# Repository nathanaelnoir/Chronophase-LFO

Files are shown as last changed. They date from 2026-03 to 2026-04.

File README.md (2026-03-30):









# Chronophase LFO

Chronophase LFO is a clock-synced Eurorack modulation source with an Arduino Nano core, four front-panel controls, one clock input, and separate unipolar, bipolar, and inverted bipolar outputs.

## Contents

- Overview
- Features
- Quick start (KiCad 9)
- Files
- Build & assembly notes
- Testing
- License & contributing

## Overview

This repository contains the KiCad 9 design files for Chronophase LFO, a clocked modulation module for Eurorack. An external clock drives the LFO core, the four main controls adjust `WAVEFORM`, `AMP`, `PHASE`, and `MODULATION`, and the output stage provides `UP_Out`, `BP_Out`, and `BP_Inv_Out` on separate jacks.

The current KiCad 9 project files are named `Synced_LFO`, and the top-level schematic title block still says `Clocked Modulation LFO`. The PCB title block currently shows revision `v0.1`, so that is the most concrete revision marker in the project as it stands.

The hardware clearly includes an `Arduino_Nano_v3.x`, but there is no firmware source in this repository at the moment, only the hardware design files.

## Features

- Clock-synced LFO built around an `Arduino_Nano_v3.x` core and `TL072` output / shaping stages.
- Four front-panel controls: `WAVEFORM`, `AMP`, `PHASE`, and `MODULATION`.
- External `CLK In` jack for sync / clock input.
- Separate `UP_Out`, `BP_Out`, and `BP_Inv_Out` outputs.
- Front-panel activity LED.
- Standard Eurorack power distribution with `+12 V / -12 V / +5 V / GND` through a 16-pin Eurorack header sheet.
- Mixed build: SMD passives, diodes, electrolytics, and SOIC op-amps, with through-hole jacks, pots, LED, and Arduino Nano.

## Quick start

1. Install KiCad 9.
2. Open the project: `KiCad/Synced_LFO.kicad_pro`.
3. Review the top-level schematic and the `EURORACK_POWER` sheet, then run ERC/DRC before exporting manufacturing files.

## Files

- `KiCad/Synced_LFO.kicad_sch` - top-level schematic
- `KiCad/eurorack_power.kicad_sch` - Eurorack power sheet
- `KiCad/Synced_LFO.kicad_pcb` - PCB
- `KiCad/Synced_LFO.kicad_pro` - KiCad 9 project file
- `KiCad/Synced_LFO.kicad_prl` - local KiCad 9 project state
- `KiCad/Synced_LFO.sch` - legacy schematic file
- `KiCad/Synced_LFO.pro` - legacy project file

Note: there is a single PCB layout file (`KiCad/Synced_LFO.kicad_pcb`) for this project.

## Build & assembly notes

- Check orientation on the `Arduino_Nano_v3.x` module before soldering headers or the board directly. The USB end and pin order matter.
- Confirm pin-1 orientation on the `TL072` packages and polarity on the diodes and electrolytics before powering the board.
- Double-check the Eurorack power header orientation before applying power. This design uses `+12 V`, `-12 V`, `+5 V`, and `GND`, so a reversed cable is an easy way to damage parts.
- Panel hardware is straightforward but still substantial: four 100 k pots, four 3.5 mm jacks, and one LED.
- This is a mixed SMD + THT build, so it makes sense to solder the low-profile SMD parts first and leave the pots, jacks, LED, and Nano for later.

## Testing

1. Power the module from a current-limited Eurorack supply and verify `+12 V`, `-12 V`, `+5 V`, and `GND` on the power section before checking the rest of the circuit.
2. Feed a known clock into `CLK In` and confirm the front-panel LED shows activity.
3. Probe `UP_Out`, `BP_Out`, and `BP_Inv_Out` on a scope and confirm all three outputs are present and distinct.
4. Turn `WAVEFORM`, `AMP`, `PHASE`, and `MODULATION` through their full range and verify the outputs respond as expected.
5. If the Arduino Nano is fitted, confirm the module behavior is stable across different clock rates and after power-cycling.

## License & contributing

No `LICENSE` file has been added to this repository yet. Until that changes, assume the design is shared for reference, not under an explicit open-source license.

If a license is added later, this section can be updated properly.

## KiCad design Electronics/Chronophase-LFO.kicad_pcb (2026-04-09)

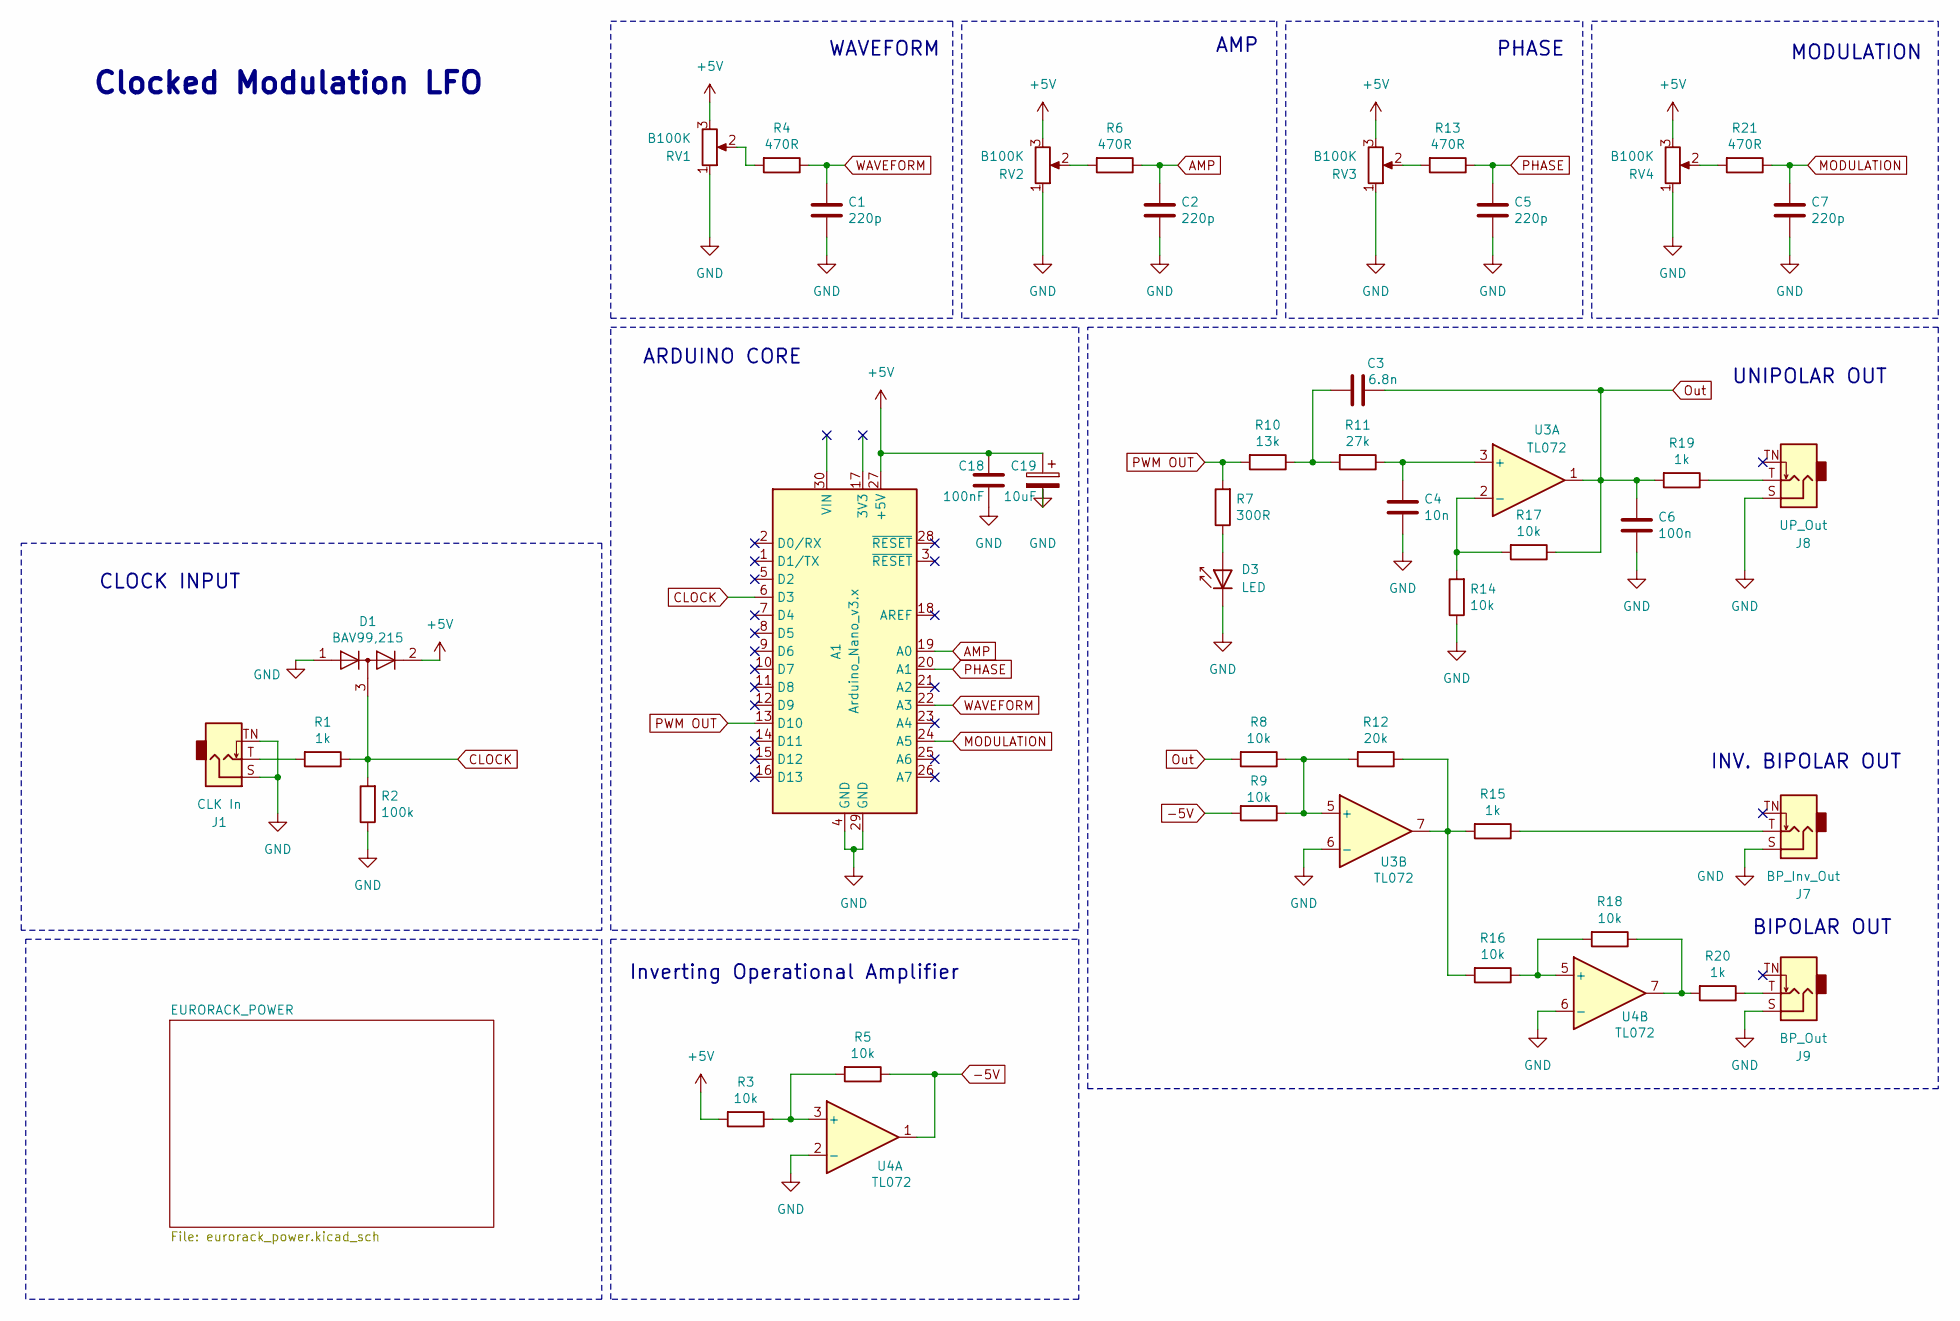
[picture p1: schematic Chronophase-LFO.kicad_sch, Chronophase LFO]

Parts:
A1: Arduino_Nano_v3.x; Arduino_Nano
C1, C2, C5, C7: 220p; C_0805_2012Metric_Pad1.18x1.45mm_HandSolder; LCSC C1530
C3: 6.8n; C_0805_2012Metric_Pad1.18x1.45mm_HandSolder; LCSC C1542
C4: 10n; C_0805_2012Metric_Pad1.18x1.45mm_HandSolder; LCSC C15195
C6: 100n; C_0805_2012Metric_Pad1.18x1.45mm_HandSolder; LCSC C1525
C18: 100nF; C_0805_2012Metric_Pad1.18x1.45mm_HandSolder
C19: 10uF; CP_Elec_5x5.4
D1: BAV99,215; SOT-23; LCSC C2500
D3: LED; LED_D3.0mm_Clear
J1: CLK In; Jack_3.5mm_QingPu_WQP-PJ398SM_Vertical
J7: BP_Inv_Out; Jack_3.5mm_QingPu_WQP-PJ398SM_Vertical
J8: UP_Out; Jack_3.5mm_QingPu_WQP-PJ398SM_Vertical
J9: BP_Out; Jack_3.5mm_QingPu_WQP-PJ398SM_Vertical
R1, R15, R19, R20: 1k; R_0805_2012Metric_Pad1.20x1.40mm_HandSolder; LCSC C11702
R2: 100k; R_0805_2012Metric_Pad1.20x1.40mm_HandSolder; LCSC C25741
R3, R5, R8, R9, R14, R16, R17, R18: 10k; R_0805_2012Metric_Pad1.20x1.40mm_HandSolder; LCSC C25744
R4, R6, R13, R21: 470R; R_0805_2012Metric_Pad1.20x1.40mm_HandSolder; LCSC C25117
R7: 300R; R_0805_2012Metric_Pad1.20x1.40mm_HandSolder; LCSC C25102
R10: 13k; R_0805_2012Metric_Pad1.20x1.40mm_HandSolder; LCSC C22797
R11: 27k; R_0805_2012Metric_Pad1.20x1.40mm_HandSolder; LCSC C25771
R12: 20k; R_0805_2012Metric_Pad1.20x1.40mm_HandSolder; LCSC C25765
RV1, RV2, RV3, RV4: B100K; Potentiometer_Alpha_RD901F_Vertical_Alt
U3, U4: TL072; SOIC-8_3.9x4.9mm_P1.27mm

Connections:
+5V: A1.27 (+5V), C18.1, C19.1, D1.2 (A), R3.2, RV1.3, RV2.3, RV3.3, RV4.3; also elsewhere on the board
-5V: R5.1, R9.2, U4.1
AMP: A1.19 (A0), C2.1, R6.1
CLOCK: A1.6 (D3), D1.3 (K), R1.1, R2.2
GND: A1.4 (GND), A1.29 (GND), C1.2, C2.2, C4.1, C5.2, C6.1, C7.2, C18.2, C19.2, D1.1 (K), D3.1 (K), J1.S, J1.TN, J7.S, J8.S, J9.S, R2.1, R14.1, RV1.1, RV2.1, RV3.1, RV4.1, U3.6 (-), U4.2 (-), U4.6 (-); also elsewhere on the board
MODULATION: A1.24 (A5), C7.1, R21.1
unnamed: C3.2, R10.1, R11.2
unnamed: D3.2 (A), R7.1
unnamed: J1.T, R1.2
unnamed: J7.T, R15.1
unnamed: J8.T, R19.1
unnamed: J9.T, R20.1
unnamed: R4.2, RV1.2
unnamed: R6.2, RV2.2
unnamed: R12.1, R15.2, R16.2, U3.7
unnamed: R13.2, RV3.2
unnamed: R18.1, R20.2, U4.7
unnamed: R21.2, RV4.2
unnamed: C4.2, R11.1, U3.3 (+)
unnamed: R14.2, R17.2, U3.2 (-)
unnamed: R8.1, R9.1, R12.2, U3.5 (+)
unnamed: R3.1, R5.2, U4.3 (+)
unnamed: R16.1, R18.2, U4.5 (+)
Out: C3.1, C6.2, R8.2, R17.1, R19.2, U3.1
PHASE: A1.20 (A1), C5.1, R13.1
PWM OUT: A1.13 (D10), R7.2, R10.2
WAVEFORM: A1.22 (A3), C1.1, R4.1

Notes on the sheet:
AMP
ARDUINO CORE
Clocked Modulation LFO
PHASE
WAVEFORM
MODULATION
INV. BIPOLAR OUT
BIPOLAR OUT
UNIPOLAR OUT
CLOCK INPUT
Inverting Operational Amplifier

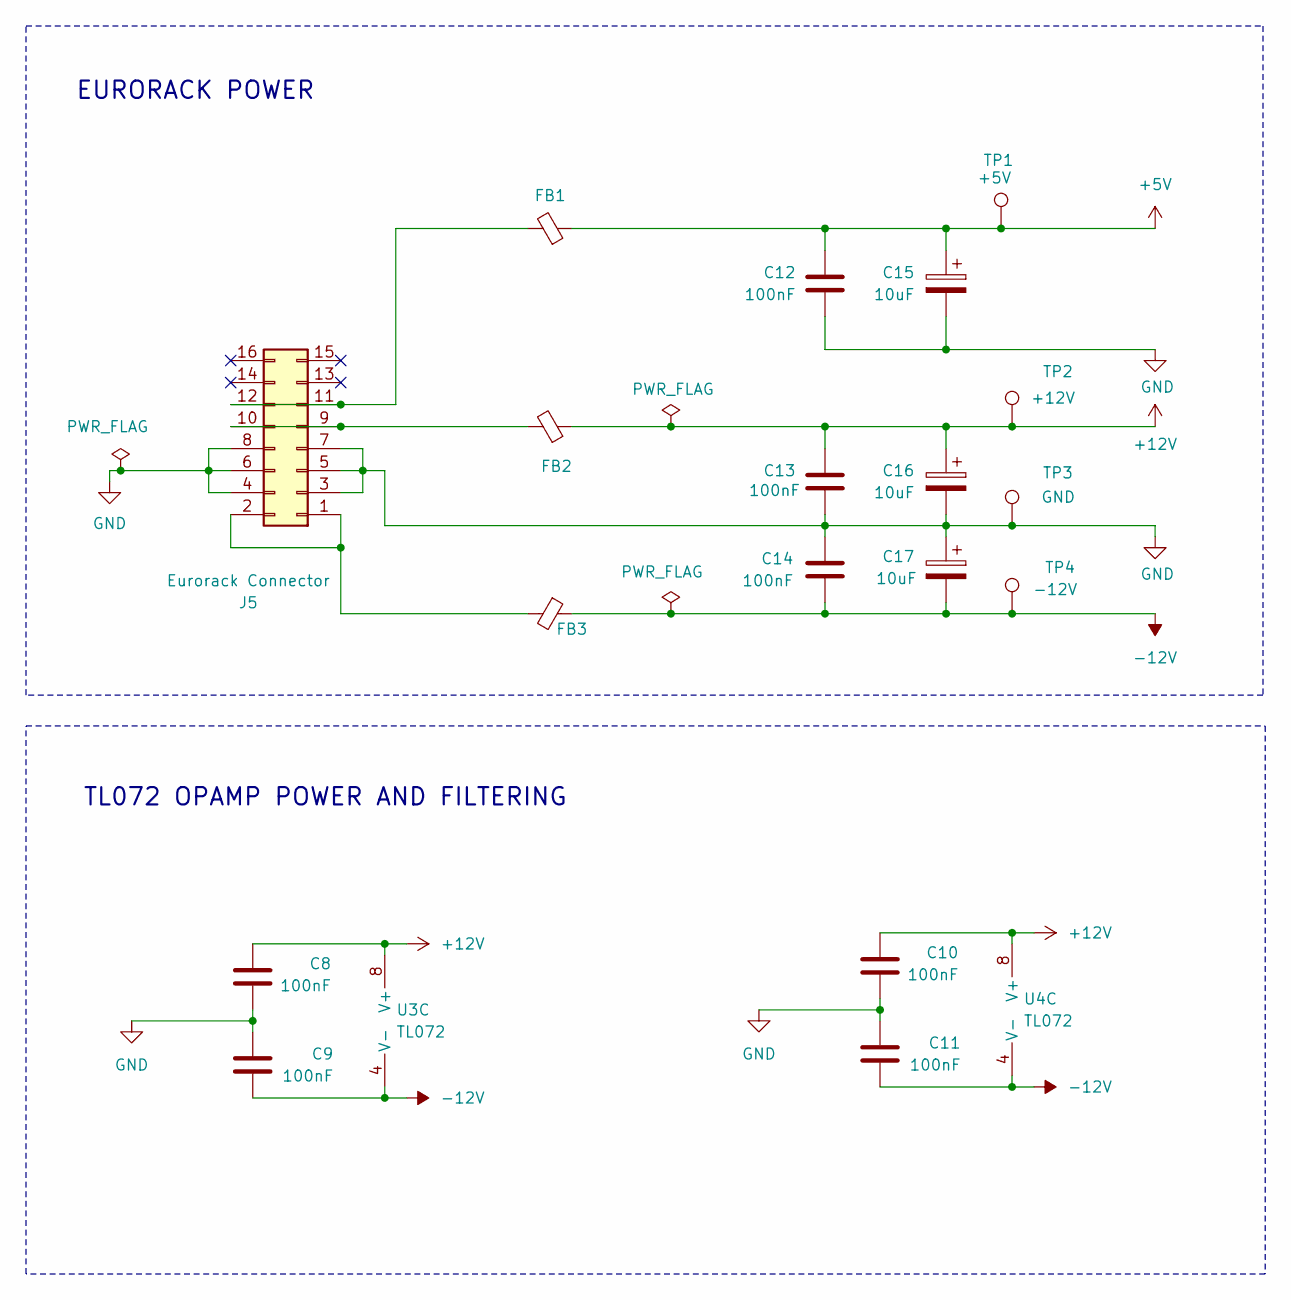
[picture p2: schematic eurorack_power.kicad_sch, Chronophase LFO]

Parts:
C8, C9, C10, C11, C12, C13, C14: 100nF; C_0805_2012Metric_Pad1.18x1.45mm_HandSolder
C15, C16, C17: 10uF; CP_Elec_5x5.4
FB1, FB2, FB3: FerriteBead_Small; L_0805_2012Metric_Pad1.05x1.20mm_HandSolder
J5: Eurorack Connector; IDC-Header_2x08_P2.54mm_Vertical
TP1: +5V; TestPoint_Pad_D1.5mm
TP2: +12V; TestPoint_Pad_D1.5mm
TP3: GND; TestPoint_Pad_D1.5mm
TP4: -12V; TestPoint_Pad_D1.5mm
U3, U4: TL072; SOIC-8_3.9x4.9mm_P1.27mm

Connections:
+5V: C12.1, C15.1, FB1.1, TP1.1; also elsewhere on the board
+12V: C8.1, C10.1, C13.1, C16.1, FB2.1, TP2.1, U3.8 (V+), U4.8 (V+)
-12V: C9.2, C11.2, C14.2, C17.2, FB3.1, TP4.1, U3.4 (V-), U4.4 (V-)
GND: C8.2, C9.1, C10.2, C11.1, C12.2, C13.2, C14.1, C15.2, C16.2, C17.1, J5.3, J5.4, J5.5, J5.6, J5.7, J5.8, TP3.1; also elsewhere on the board
unnamed: FB3.2, J5.1, J5.2
unnamed: FB2.2, J5.9, J5.10
unnamed: FB1.2, J5.11, J5.12

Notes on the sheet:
TL072 OPAMP POWER AND FILTERING
EURORACK POWER

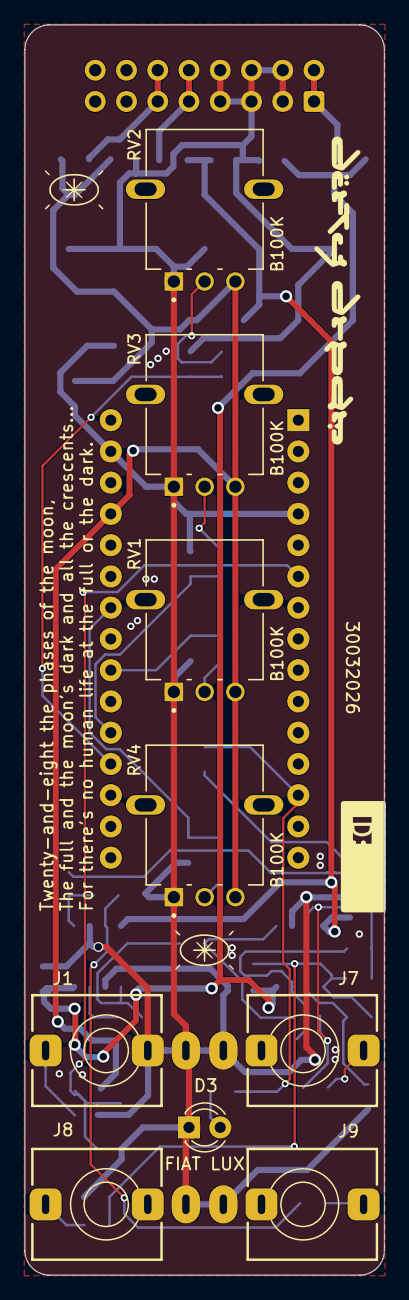
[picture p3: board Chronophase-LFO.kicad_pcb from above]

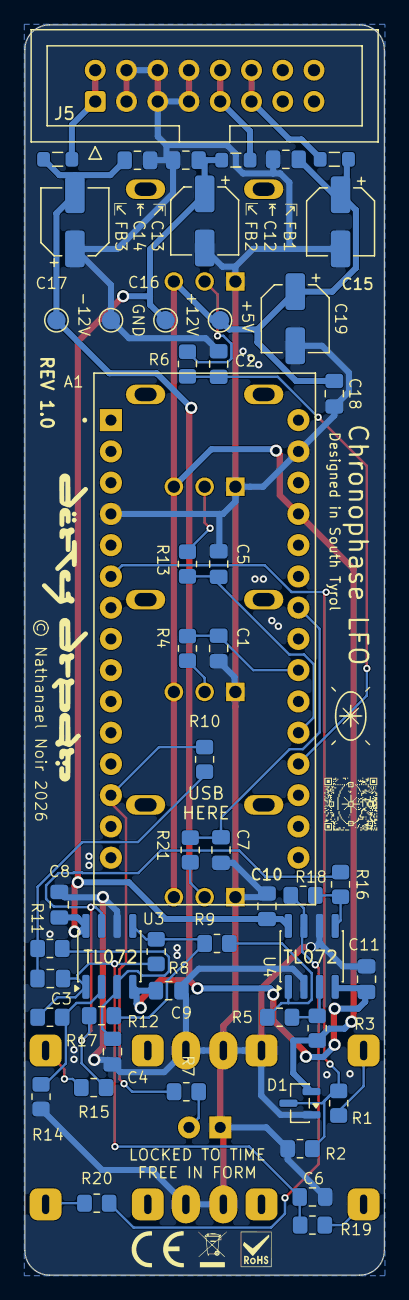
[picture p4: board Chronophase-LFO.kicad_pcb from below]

Board: 2 copper layers, 29.2 x 101.6 mm, 61 parts (52 on the bottom side), 32 nets.

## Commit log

2026-03-13 first commit message
    [Synced_LFO.kicad_pcb, Synced_LFO.kicad_sch, Synced_LFO.sch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]
2026-03-13 Added new Powerrail and fixed ERC Error
    [Synced_LFO.kicad_sch, untitled.kicad_sch]
2026-03-25 chore(kicad): update project settings and board view state
2026-03-28 adding footprints
    [Synced_LFO.kicad_sch, eurorack_power.kicad_sch]
2026-03-28 adding last missing footprints
    [Synced_LFO.kicad_sch, eurorack_power.kicad_sch, untitled.kicad_sch]
2026-03-29 fixing power in sch; placing components; connecting pads and coppering
    [Synced_LFO.kicad_pcb, Synced_LFO.kicad_sch, eurorack_power.kicad_sch]
2026-03-30 adding Logos on the pcb board
    [Synced_LFO.kicad_pcb]
2026-03-30 docs: add Chronophase LFO README based on module template
    [Synced_LFO.sch]
2026-04-01 generating gerber files
    [Synced_LFO.kicad_pcb]
2026-04-01 adding new logo
    [Synced_LFO.kicad_sch, eurorack_power.kicad_sch]
2026-04-02 changing folder names
    [Synced_LFO.kicad_pcb, Synced_LFO.kicad_sch, eurorack_power.kicad_sch]
2026-04-02 changing file names
    [Chronophase-LFO.kicad_pcb, Chronophase-LFO.kicad_sch]
2026-04-09 Updating to KiCad 10
    [Chronophase-LFO.kicad_pcb, Chronophase-LFO.kicad_sch, eurorack_power.kicad_sch]

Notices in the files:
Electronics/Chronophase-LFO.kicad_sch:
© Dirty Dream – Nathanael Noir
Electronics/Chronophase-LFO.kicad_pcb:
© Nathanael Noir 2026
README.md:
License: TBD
